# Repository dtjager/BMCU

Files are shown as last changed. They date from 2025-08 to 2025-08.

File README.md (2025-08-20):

My collection of resources for my x1c BMCU build. I noticed everything is not necessarily the easiest to find/sort out, so I put things here as I found them.

[BMCU Wiki](https://wiki.yuekai.fr/)

[Subreddit](https://www.reddit.com/r/BMCU/)

[OpenBambu Subreddit](https://www.reddit.com/r/openbambu/)

[Parts kit I ordered](https://www.aliexpress.us/item/3256809034433237.html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) - 370C A Kit, needed to order PCB's anyway so I figured this was probably the easiest route.

[Filamentalist](https://makerworld.com/en/models/1415066-filamentalist-fv3-rewinder-pc4-m6-mod#profileId-1469469) - for filament rewinding no the X1/P1 printer.

Notes:

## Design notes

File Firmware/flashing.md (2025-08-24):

If you did **not** solder the motherboard yourself, flashing is usually **not required**. Unless you want to upgrade the firmware.

[¶](#️-warning) ⚠️ **WARNING**
------------------------------

🔥 **Before flashing, ensure there are no soldering issues!!!! Check for power short circuits!!!!** 🔥  
🔥 **Before flashing, ensure there are no soldering issues!!!! Check for power short circuits!!!!** 🔥  
🔥 **Before flashing, ensure there are no soldering issues!!!! Check for power short circuits!!!!** 🔥  

[¶](#required-tools) **Required Tools**
---------------------------------------

1.  **Multiple Dupont Wires** (To connect the flasher and the BMCU mainboard).
2.  **USB to Serial Adapter**
3.  **Computer** runs windows. -> If you're using a Mac/Linux, flashing is possible, but I don't have any tutorials or resources for mac.
4.  **Software: WCHISPTool**  
    The classic version used in this tutoriel : [wchisptool-v3.3.7z](/assets/files/wchisptool-v3.3.7z)  
    A newer version : [download at WCH website](https://www.wch-ic.com/downloads/WCHISPTool_Setup_exe.html)

[¶](#flashing-with-uart-ttl-using-ch340) Flashing with UART (TTL) using CH340
=============================================================================

### [¶](#h-1-connect-the-bmcu-mainboard-and-usb-serial-tool) 1. **Connect the BMCU Mainboard and USB Serial Tool**

⚠️ **DO NOT connect the BMCU to the printer during the entire process!**

*   Open the software  
    
    
*   Connect wires according to the wiring instructions.
    
    BMCU
    
    USB Serial Tool
    
    R
    
    TXD
    
    T
    
    RXD
    
    ➕
    
    3V3
    
    ➖
    
    GND

> You may receive a yellow jumper cap, if it is similar to the converter on the right, no need to use it.  
> Connect 3.3V as VCC to the '+' pin on the BMCU mainboard.

  


> If you don't see a serial device here, please install the CH340 chip driver  
> [https://www.arduined.eu/ch340-windows-10-driver-download/#google\_vignette](https://www.arduined.eu/ch340-windows-10-driver-download/#google_vignette)

### [¶](#h-2-connect-the-usb-serial-tool-to-your-pc) 2. **Connect the USB Serial Tool to Your PC**

*   Your computer should recognize the serial port automatically.
*   The COM port number might differ from the example in the image.



* * *

### [¶](#h-3-configure-wchisptool-settings) 3. **Configure WCHISPTool Settings**

Open the `WCHISPTool` software and set the following options:

*   **Chip Model:** `CH32V203`
*   **Download Type:** `SerialPort`
*   **DI – Baud Rate:** `1M`
*   **SerialPort:** Auto-detected (your COM port)
*   **User File:** Choose the firmware `.bin` file (available from our wiki)



* * *

### [¶](#h-4-unlock-the-chip-protection) 4. **Unlock the Chip Protection**

This is a **critical step** before flashing the firmware.

#### [¶](#recommended-method) ✅ Recommended Method:

1.  **Hold down the B button** (do **not** release it throughout).
2.  While holding B, **briefly press the R button** once.
3.  While **still holding B**, click the **"Remove Protect"** button in the WCHISPTool software.  
    

If successful, you’ll see a red **“Unlocked”** message in the tool.  
remove protect successful.png

> ⚠️ If it keeps failing:  
> If you build your own PCB, please always check first for any soldering issues, such as solder bridges on resistor arrays, solder bridges on the CH32V chip, or short circuits in the circuit.
> 
> *   First, try again using the same button sequence carefully, hold always the B button.
> *   Second, **double-click the “Download” button** to force the chip into response mode, then try "Remove Protect" again.
> *   （Rare but indeed some chips will perform like this) try **swapping the TX and RX wires** (i.e., TX-to-TX and RX-to-RX instead of cross).

* * *

### [¶](#h-5-flash-the-firmware) 5. **Flash the Firmware**

Click the **Download** button.

*   Be patient during the process.
*   If flashing is successful, it should look like this:  
    

#### [¶](#️-if-flashing-fails) ⚠️ If Flashing Fails:

*   Try **pressing and holding the B button** while clicking “Download”.
*   Alternatively, try changing the **baud rate to 115200**.
*   In rare cases, try **reversing TX and RX** (TX-to-TX, RX-to-RX) if not already done.

* * *

### [¶](#h-6-reboot-the-board) 6. **Reboot the Board**

*   Press the **R button** once.
*   The **red LED on the mainboard** should now light up.
*   🎉 **Congratulations! Firmware flashing is complete!** 🎉

[¶](#with-type-c-interface) With Type-C interface
=================================================

### [¶](#open-the-software) Open the software



### [¶](#configure-wchisptool-settings) Configure WCHISPTool Settings

Open the `WCHISPTool` software and set the following options:

*   **Chip Model:** `CH32V203`
*   **Download Type:** Still `Serial Port`
*   **DI – Baud Rate:** `1M`
*   **User File:** Choose the firmware `.bin` file (available from our wiki)
*   Tick the "Serial Auto DI" option.



### [¶](#action-sequence) Action sequence

Click : `Remove Protect` -> `Download` -> `Remove Protect` Again -> `Download` Again -> Repeat this loop until done(normolly the second download will be successful, if not check if you done something wrong)  
You might see some error messages during the first loop.

[¶](#using-mac-linux) Using Mac / Linux
=======================================

todo

[¶](#testing) Testing
=====================

**⚠️⚠️⚠️Avoid hot plugging and unplugging the motherboard and printer cables.⚠️⚠️⚠️**  
The right approach（just in case you are not sure what to do):

1.  Power off the printer
2.  Connect the BMCU to the printer
3.  Switch on the printer power
4.  You should see AMS appear in the consumables option, even if you have not inserted consumables, it may show that consumables are present in some channels (known bug)
5.  Power off the printer
6.  Disconnect the BMCU cable

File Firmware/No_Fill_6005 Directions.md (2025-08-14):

Thinking about getting a BMCU? What I've learned!

**Disclaimer:** I'm extremely new to the BMCU system and just finished putting mine together today, so take everything that I say with a grain of salt and proceed at your own risk. With this being said, there were a couple of times throughout the process where I was stumped, so I'd like to share what I've learned and I'll update this post if I ever have to troubleshoot in the future. Just for reference, I have an A1. Also, most of what I write below will be in reference to the version that I have from the specific seller that I bought it from, as well as mostly for the A1. Please let me know if I am wrong about anything that I wrote below, as I just want to make sure that people have an easy introduction into the BMCU.

**Please read my points number 28 and 39 before you even attempt to assemble the BMCU!**

**1\. What is the difference between the BMCU and AMS?** The BMCU and AMS will give you the same results: multi-color printing. However, with this being said, the BMCU is an open-source, non-official Bambulab product. So, technically, Bambu can theoretically release updates that prevent the system from working. But fortunately, as of now, you can always revert back to previous updates on Bambu.  

**2\. What versions does the BMCU work on?** According to the seller that I bought it from, it works with the A1 and A1 mini. It also experimentally works with the P1S P1P, which you can find posts about in the reddit groups that I have listed below. Additionally, it could possibly work with the X1 series but it is unproven.  

**3\. If it's open source, can I just order all the parts separately myself?** Yes, people have done so in the groups that I have listed below, but I personally have not. The good thing about this is that if you order a kit and accidentally break a piece, you can order a specific replacement part (usually for pretty cheap). And just so you know, people also upload replacement pieces on MakerWorld.  

**4\. What's the difference between a BMCUx and BMCUc?** The BMCUc supports bi-directional buffering, making the system softer on your printer.  

**5\. What are some of the other BMCU options?** Some BMCUs use a 130 motor while others use a 370 motor. Additionally, some use glass bearings and some use steel bearings. I'm not really sure what the difference is, but the one I ordered has a 370 motor and glass bearings.  

**6\. Where did you buy yours from?** I bought Set A from this link: [**https://www.aliexpress.us/item/3256809034433237.html?spm=a2g0o.order\_list.order\_list\_main.5.49ea1802L3PVEx&gatewayAdapt=glo2usa#nav-specification**](https://www.aliexpress.us/item/3256809034433237.html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)  

**7\. What is the difference between Set A vs Set C?** Set A is for those that want to print in up to 4 colors. Set C is typically bought by those that have print farms and only want the option of having two spools in case one runs out as a backup, because to them, time is money, rather than having the option of printing 4 colors.  

**8\. How hard is it to assemble?** Not hard at all, _but you'll need a soldering iron and solder (aka wire meant for soldering)._ If it's your first time soldering, don't worry. It was my first time ever dealing with electronics or soldering. I'll post some reference videos below. Also, here are some tools that I would recommend printing to help you with soldering. Links: [https://www.printables.com/model/843353-solder-scroll-ergonomic-adjustable-solder-tool](https://www.printables.com/model/843353-solder-scroll-ergonomic-adjustable-solder-tool) and [https://makerworld.com/en/models/487984-soldering-tool-holder-flexible-arms-helping-hands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](https://makerworld.com/en/models/487984-soldering-tool-holder-flexible-arms-helping-hands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)  

**9\. Why does the seller that you bought it from have another kit with the same title and description, but sometimes different prices?** To be honest, no idea. But, if someone knows why, post it in the comments of this post so that others can learn from it.  

**10\. Where can I find the instructions for the kit that you purchased?** This drive contains the instructions, firmware, and STLs from the seller. Also, people recommend to print the pieces in PETG. Link: [https://drive.google.com/drive/folders/1XAFt80xYqbaAVDwtqItvBLUezMbsYlGM](https://drive.google.com/drive/folders/1XAFt80xYqbaAVDwtqItvBLUezMbsYlGM)

**11\. I'm limited on space. Is there a print that will allow me to mount both the spools and the BMCU on my A1?** Yup, there sure is! Go to the link I will paste, print it out of PETG, and select the print profile by me, TheHerd, on MakerWorld, if you have an A1 and are confused about which pieces are compatible with it and don't feel like arranging the pieces to fit on your A1 build plate. Don't worry, the original creator still gets the points. And, instead of screwing it, I used mounting tape from the Gorilla brand because I didn't want to risk my model not being compatible with where they wanted me to screw it in. And, just and fyi, it is fine to print out the PTFE supports with PLA instead of PETG. You can find that stl in the Google drive folder that I posted the link to in my 10th bullet point. Link: [https://makerworld.com/en/models/1429013-bmcu-stand-for-a1-a1-mini-ams-lite-vertical-mount#profileId-1485599](https://makerworld.com/en/models/1429013-bmcu-stand-for-a1-a1-mini-ams-lite-vertical-mount#profileId-1485599)  

**12\. Won't adding all that weight be rough on my printer?** Probably, so you may want to print out these Z-axis supports in PETG from the link I will paste if you have an A1. Print the print profile that is titled "A1 mini Big feet" instead of the one from the creator, as you only need the bottom part. Don't worry about the title saying it's for the mini. Link: [https://makerworld.com/en/models/92486-ams-lite-top-mount-for-a1#profileId-100105](https://makerworld.com/en/models/92486-ams-lite-top-mount-for-a1#profileId-100105)

**13\. Where are some good resources if I want to ask questions about the BMCU?** [https://www.reddit.com/r/OpenBambu/](https://www.reddit.com/r/OpenBambu/) and [https://www.reddit.com/r/BMCU/](https://www.reddit.com/r/BMCU/)  

**14.** **One of the bushings that BLV mentioned in Step 4 of the assembly guide isn't fitting. What do I do?** Yup, and it won't ever fit perfectly in there for some reason, no matter how many times you reprint the STL. Not saying that you should superglue it, but that's what I did. Try and find glue that is heat and vibration resistant.  

**15.** **I'm on Step 5 of the assembly guide and don't know how to solder. Help!** First of all, I'd recommend using the part of the tool that I have the arrow point to to strip the wire. Place the wire where the arrow is pointing, then pull it. Second of all, personally, before I add solder to the wire, I twist the "hairs" so they aren't "frazzled". Make sure to strip and add solder to both ends of the wire. It's a surprise tool that will help us later. Here's the link that I used to learn how to solder for the motor: [https://youtu.be/XkpGsMpGGqQ?si=qGBOIP5blRSgvldF](https://youtu.be/XkpGsMpGGqQ?si=qGBOIP5blRSgvldF) . While the video says to place the black wire on the red dot, and it technically doesn't matter if you solder it to the negative on the daughter board. However, I'd highly recommend just keeping it aligned with the instructions and SOLDERING RED TO RED.

r/OpenBambu - Thinking about getting a BMCU? What I've learned! (https://preview.redd.it/thinking-about-getting-a-bmcu-what-ive-learned-v0-tdrll9tojlff1.png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 "Image from r/OpenBambu - Thinking about getting a BMCU? What I've learned!")

**16\. I'm on Step 8 of the assembly guide. What does BLV mean when they say "with the pointed end facing up"?** They just mean to place the hex nut in vertically rather than horizontally.  

**17\. I'm on Step 9 and the slider isn't moving easily.** **What do I do?** You likely just need to shave the sides of the slider. I used a wood carving tool, personally, but you can probably just file it down or use sand paper.  

**18\. What in the world is BLV talking about in Step 10?** In the bag, there are two pieces that look very similar and seem to have the same diameter. For this step, the assembly guide is wanting you to take out the one with the black screw on the side. You'll have to take out the screw before you can insert the shaft then screw it back once you've already inserted it.  

**19\. In Step 12, does the filament seem to face a little resistance even though I can still push it through?** Yup, you didn't do anything wrong. There are little teeth inside of the metal outlet that causes this.  

**20\. I'm on Step 20 of the assembly guide. How do I do this now?** Watch this video. It is okay if you get some metal on the black part, but make sure not to let the metal from the positive end and negative end touch one another. [**https://youtu.be/y0xDR3St5Gg?si=RhCsTe45R3gjiS3f**](https://youtu.be/y0xDR3St5Gg?si=RhCsTe45R3gjiS3f)  

**21\. I accidentally got grease on the end of the solder wire. What do I do?** Use some rubbing alcohol to wipe, get a clean napkin and wipe off the alcohol, then wait for the rest to evaporate. The alcohol will evaporate quickly.  

**22\. In step 22, it says that I should feel a bend. What bend?** You'll just feel a slight resistance, but not anything that screams "bend".  

**23\. Did you have leftover parts when you finished?** Yup!  

**24\. When you plug in the BMCU, which port on the back of the A1 do you use?** Doesn't matter, they're the exact same!

**25\. Why is the AMS screen on my printer appearing but not giving me any options to load, unload, or edit?** You have to push the filament all the way through the BMCU first, but don't go all the way to the actual print head. Once you pass it through the BMCU, you'll have the options to load, which is when you need to push it all the way to the print head.

**26\. Huh, what do they mean in step 27 when they say to push on the slider vs when they say to pull on the slider?** So, what the assembly manual really means, is that you need to push down on the trigger thingy until the printer says that it has finished loading. If you release the trigger before it has completed loading, it will pull the filament back towards the spool rather than towards the print head. With this being said, before you actually load the filament (refer to my 25th point), you need to press the trigger just to load the filament all the way through the BMCU. After doing so, you can release the trigger. Then, on the printer, click load. One the screen says to push in the filament, you MUST press the trigger the entire time while you are pushing it through the print head. Keep holding it until it moves on to the purge step. After it reaches the purge step, you can release the trigger.  

**27\. In step 30 of the assembly guide, when it says to not cut the PTFE tubes too short, what exactly does that mean?** So, quick tip, I went to "controls" on the printer and moved the hot end all the way to the left because the furthest slot was towards the right. That gave me the maximum length that I needed for the PTFE tube, roughly. Make sure to account for the fact that a small portion of the tube will be hidden in the BMCU and print head. For the mount that I pasted a link to, I put the mount roughly in the middle (I tried to center it but it was a little to the left), and the longest strand I need was 33 inches.

**28\. How do I remove the cord from the back?** _BEFORE YOU EVEN PLUG IN THE BMCU, PRINT THIS TOOL TO REMOVE THE WIRE!!!!_ Even with this tool, I had to use quite a bit of force, and I tend to be rough on things. I printed the tool out of PETG and used 100%% infill. Link: [https://www.printables.com/model/382058-bambu-ams-disconnect-tool](https://www.printables.com/model/382058-bambu-ams-disconnect-tool)

**29\. When I try to unload filament, it just pushes more filament further**. **What do I do?** When you unload the filament, when it says to "pull back current filament" on the printer screen, you have to press the trigger.

**30\. I'm trying to unload the filament and I am pressing the trigger, but it still won't let me unload it. What do I do?** Turn off your printer then unplug the cord from the back (reference my 31st bullet). After doing so, turn your printer back on. Then, even though the AMS option won't show up, this is what we want. Click unload filament from a single roll like you had done before the BMCU. This will allow you to remove all the filaments. When finished removing the filament, turn your printer off again, then plug the BMCU back in, turn the printer on and proceed normally.

**31\. The printer keeps clogging. Help!** It is probably because even regular AMS systems are known for clogging what is apparently called "the filament hub". I didn't think that mine was clogged, and nothing seemed to have come out, but it apparently worked. Watch this video to see how to unclog it. The video also features unclogging the hot end. If it is your first time removing the filament hub, you're probably going to have to use a little more force than what's shown in the video. Link: [https://www.youtube.com/watch?v=cNBu2mcOH8E](https://www.youtube.com/watch?v=cNBu2mcOH8E) . Also, if you notice that the filament seems brittle, dry it. I noticed that PLA I had never had problems with in the past kept breaking. If you need a dryer, I would recommend buying one from Creality. While I have heard not to buy printers from them, their dryers work fine. Sometimes, people sell them for really cheap on Facebook Marketplace (saw one for $25).

**32\. How do I actually load all 4 spools?** Someone had to help me with this, and I still probably added too many extra steps for myself, but here is what I did, and it at least worked. LOL

*   Press down on the trigger and push the filament into the bottom of the module you’re trying to load. Keep going until the filament light turns on. (Earlier, I mentioned pushing it until you can see it come out the other side—sometimes the filament can get stuck in the buffer section with the spring, so just make sure it’s made it through.)
    
*   If you just want to check that the module works, you can load the filament straight into the extruder using the printer’s touchscreen—no need to mess with the slicer yet.
    
*   Once you’ve tested that loading and unloading works for all the modules, go ahead and unload the last filament you tested. If I remember right, it won’t fully eject—and that’s okay. Just leave it as is.
    
*   Turn off the printer, then push filament through the BMCU for all modules, but not all the way to the print head. Then, turn the printer back on.
    
*   Now you can go into Bambu Studio, pick the filament or filaments you want to use, and start your print. The printer will take care of all the loading and unloading automatically based on what you picked.
    
*   Make sure that the filament type that you enter into the slicer is the same as the filament AMS screen on your printer (even though you should NOT click "load"). Just click "edit"

**33\. Why in the world will the PTFE tubes not stay connected to the filament hub?!** This is apparently another common problem even with the official AMS. It will seem unreasonably difficult to pull apart if it is your first time removing it. Watch this video: [https://www.youtube.com/watch?v=hmByMHddxLE](https://www.youtube.com/watch?v=hmByMHddxLE)

**34\. I took out the hot end and now I can't get the latch back on, what do I do?** I don't know why this works, but it does. On your printer, go to "Control", click "Nozzle", then enter 200. Once you see that the nozzle has heated up to 200 degrees, use pliers to close the latch. BE CAREFUL! IT WILL BE HOT!! Once you've gotten the latch on, change the nozzle temperature to 0 degrees. Don't worry, it won't actually change it to 0 degrees, it will just stop applying heat so that the hot end will reach room temperature. I'd also recommend printing a fan cover for the side of the A1 print head, as I always tend to try to grip there. It shouldn't be hot, but I don't want to wear out the motor by accidentally stopping the fan with my hands.

**35\. Why did the motor of one of the modules stop running when trying to feed filament?** Turn off the printer and remove the PTFE tube from the print head. Hold the trigger of the module and try manually feeding it through the tube. If it is hard to do, you have a bend in your PTFE tube. Try to unbend it, then if you can't, cut it.

**36 I'm trying to print a multicolor model. Why do the colors look fine in the "Prepare" tab but change when I go to the "Preview" tab?** The "Preview" tab colors aren't the actual colors that the model will be printed in. The colors just represent different parts of the print, such as thin walls, overhang, etc.

**37\. How do I "color" my models for the BMCU?** This video helped me: [https://youtu.be/5aJZyhfY74s?si=KYn5aTZj5bulu6uI](https://youtu.be/5aJZyhfY74s?si=KYn5aTZj5bulu6uI)

**38\. How do I "color" prints that are flush, like logos?** Here's a detailed, yet short video: [https://www.youtube.com/watch?v=em\_t5sK13CM](https://www.youtube.com/watch?v=em_t5sK13CM)

**39.** **Are there replacement pieces that I should print just in case?** Yes, there absolutely are! I'd recommend printing a spare of each of these before even attempting to connect the BMCU to your printer.

*   Filament hub cap: [https://makerworld.com/en/models/745171-ams-lite-hub-cap-4-way-replacement-a1#profileId-1072550](https://makerworld.com/en/models/745171-ams-lite-hub-cap-4-way-replacement-a1#profileId-1072550)
    
*   Filament hub connector: [https://makerworld.com/en/models/1105767-bambu-ams-lite-filament-hub-connector#profileId-1173093](https://makerworld.com/en/models/1105767-bambu-ams-lite-filament-hub-connector#profileId-1173093)

Please make sure to print the spare filament hub cap and filament hub connector. The below aren't necessary, but are definitely recommended to help prevent you from needing a spare in the first place.

*   Filament hub connector and PTFE tube removal tool: [https://makerworld.com/en/models/1267494-amazing-a1-and-a1-mini-ams-hub-tool#profileId-1293506](https://makerworld.com/en/models/1267494-amazing-a1-and-a1-mini-ams-hub-tool#profileId-1293506)
    
*   Cable Clips: [https://makerworld.com/en/models/1277493-a1-cable-clip-1-1-replacement?from=search#profileId-1305146](https://makerworld.com/en/models/1277493-a1-cable-clip-1-1-replacement?from=search#profileId-1305146)

Hopefully this helps someone :)

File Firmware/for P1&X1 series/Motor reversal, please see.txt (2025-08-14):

If your motor always rotates in the opposite direction under the current firmware, even if there is nothing wrong with your wiring, please solder the motor wires in reverse before using it, unless this problem is fixed in future firmware (the function of automatically determining the forward and reverse direction is removed).

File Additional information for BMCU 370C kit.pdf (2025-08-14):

## ·Additional information for BMCU 370C TL kit

1. The kit you purchased is BMCU370C derived from the open

source BMCU project. Although the 130motor version release

first, but the official no longer provides follow-up development.

Future versions will mainly be based on the 370motor version.

The BMCU project address is here: https://bmcu.wanzii.cn

2. This kit (BMCU370C-TL) adds a rod guide to the original to

smooth the action and extend life, all other parts are the same as

the original version, if you want to assemble it strictly according to

the parts of the original version.

3. This is not an officially certified project by Bambu-Lab, so it may

become unusable at any time due to the printer's firmware

upgrade. We do not make any form of guarantee for this.

4. Due to regulations regarding mailing packages, some kits may

not contain grease. You will need to find a bit of grease that is

suitable for plastic gears. We already put some grease on the

gears, so it doesn't matter if you can't find the grease.

5. The control boards have been flashed with firmware before

shipping. And they have been fully tested.

6. Warning: Always turn off the power before plugging or

unplugging the AMS cable, otherwise it may cause permanent

damage to the printer or BMCU.

7. Warning: Before you turn off the printer, make sure that no

filament is loaded into the tool head. Otherwise, when you load

or unload the filament again when you turn on the printer next

time, the error warning "Falled to check the filament location" will

appear.

8. The kit file download link:

https://drive.google.com/drive/folders/1XAFt80xYqbaAVDwtqItvBLUezMbsYlGM

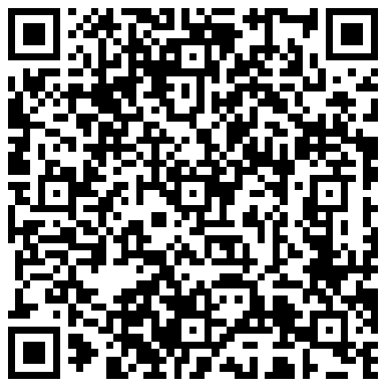
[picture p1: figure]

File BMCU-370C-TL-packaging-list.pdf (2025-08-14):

| Component | Qty.
Electronics | RF370 DC motor 24V 6000RPM | 4
| Mother board (type-C) | 1
| Daughter board (BMCU370C) | 4
| 10P Rainbow cable | 4
| AMS Connecting cables 80cm | 1
| Motor wires | 0.5M
Filament drive gear | Filament drive gear (bmg sytle) | 8
| Needle Roller Bearings | 8
| 682A Worm gear | 6
| 182A Gear | 12
| 62B Bushing | 40
| Shaft D5L22mm | 4
| Shaft D3L20mm | 4
| Shaft D2L20mm | 16
| Shaft D2L40mm | 4
| Bearings MR85ZZ | 8
Fastener | M3*5 Flat head screw | 4
| M3*14 Countersunk screws black | 5
| M3 hex nut black | 5
| M2*8 Countersunk self-tapping screws | 60
| M3*14 Countersunk self-tapping screws | 8
Misc | Spring 0.8D12L25 | 8
| Spring 0.6D4L15 | 4
| Spring 0.3D4L5 | 4
| Transparent filament 50CM | 1
| PC4-M6 Pneumatic Connector | 8
| D6H2.5 Radial Magnetic Field Magnet | 4
| D3H10 Magnet | 8
| D5 Glass ball | 6
| PTFE TUBE 4*2.5MM | 5M
version 19-6-2025

## BMCU 370C TL 4-Channel MMU for A1&P1 Series printer-Packaging-List

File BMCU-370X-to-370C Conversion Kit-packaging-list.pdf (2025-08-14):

Component | Qty.
Daughter board (BMCU370C) | 4
10P Rainbow cable | 1
62B Bushing | 10
Shaft D2L40mm | 4
M2*8 Countersunk self-tapping screws | 4
Spring 0.8D12L25 | 8
Spring 0.3D4L5 | 4
Transparent filament 50CM | 1
D3H10 Magnet | 8

## BMCU-370X-to-370C Conversion Kitpackaging-list

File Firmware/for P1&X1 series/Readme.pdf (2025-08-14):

This version of the firmware of BMCU370C is divided into

two 4-in-1 series, internal and external. If you want to install

the 4-in-1 adapter near the print head, similar to the style

of A1(Figure 1), so that you can change the filament as

quickly as possible, then you have to flash the internal

version of the firmware. If you install the 4-in-1 adapter

outside the chassis, similar to the traditional AMS used by

P1X1, then you have to flash the external firmware (Figure

2).

The same version of the firmware has four suffix ABCD,

which are used to distinguish the identification numbers of

four different BMCUs connected in parallel on the same

printer. In other words, you can install four BMCUs on your

P1X1, flash the four firmwares ABCD respectively, and

simply connect the cables in parallel to achieve the AMS

function of 16 channels. (Figure 3). Please do not try this on

the A1/A1 mini, as it is not possible for the A1 to support

more than 4 channels.

Figure 1:

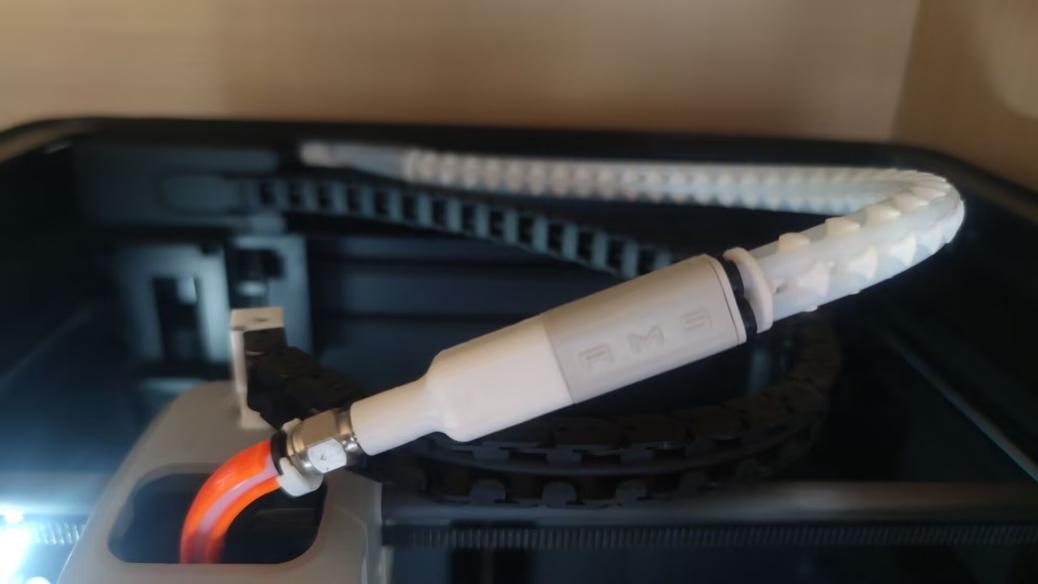
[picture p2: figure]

Figure 2:

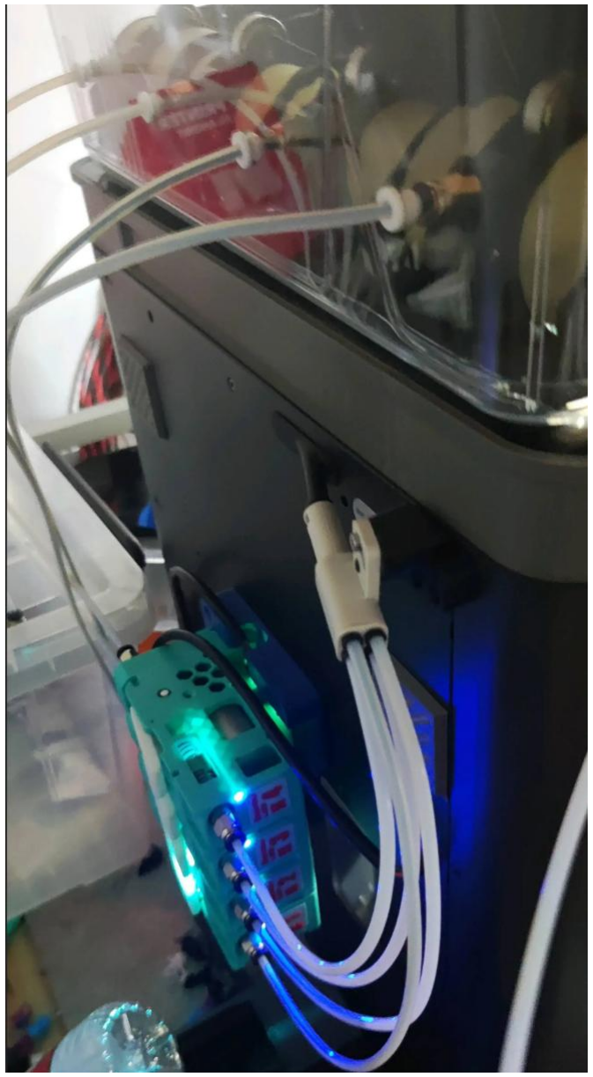
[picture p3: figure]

Figure 3:

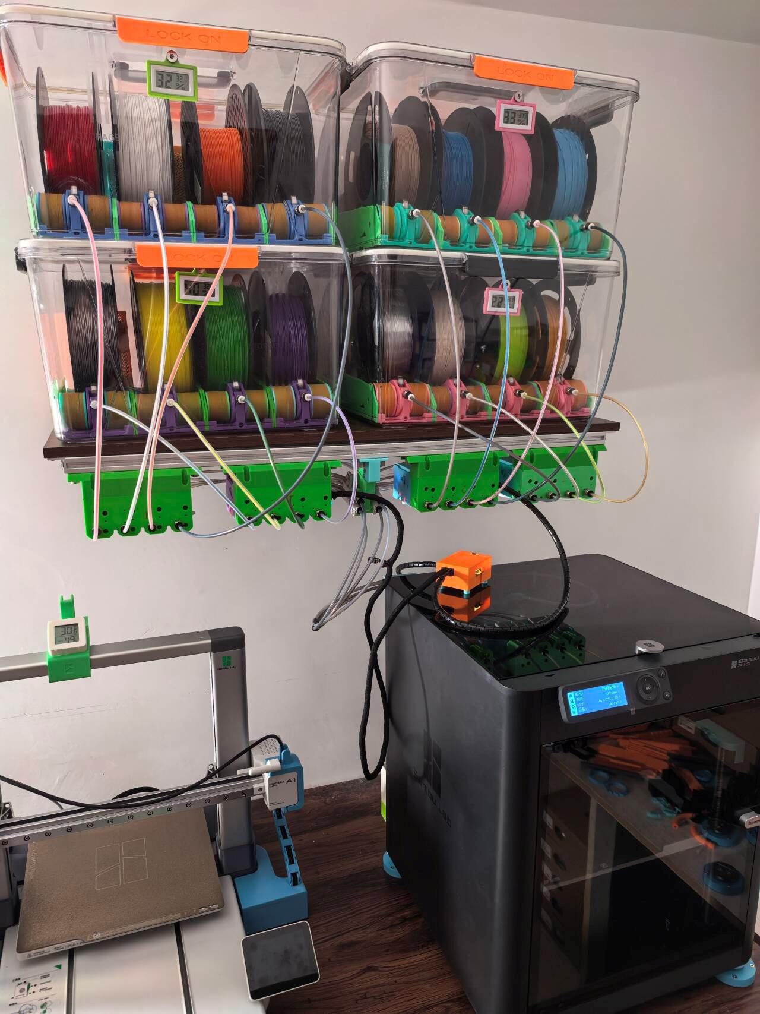
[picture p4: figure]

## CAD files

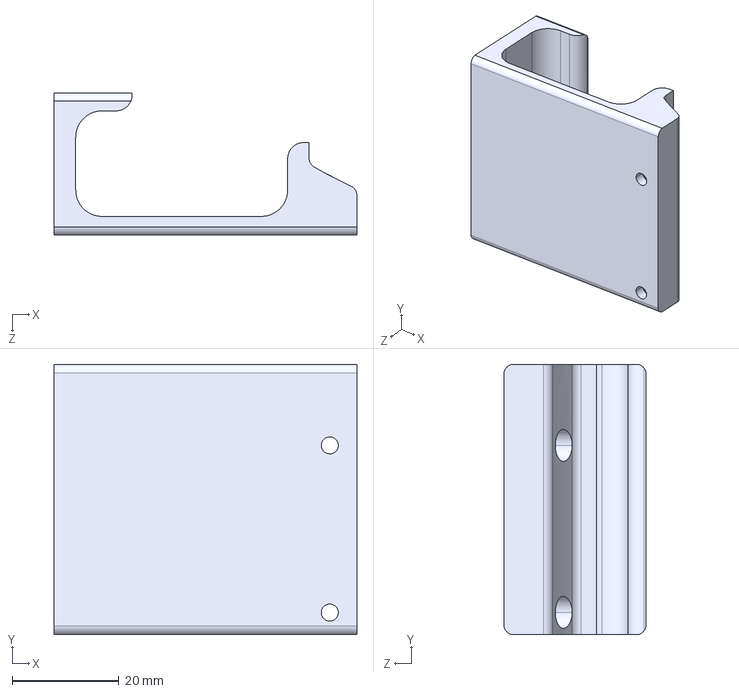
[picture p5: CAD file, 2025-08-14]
STL's/Accessories and Mounting Brackets/Mounting Bracket for A1.STEP
56.9 x 50.7 x 26.7 mm

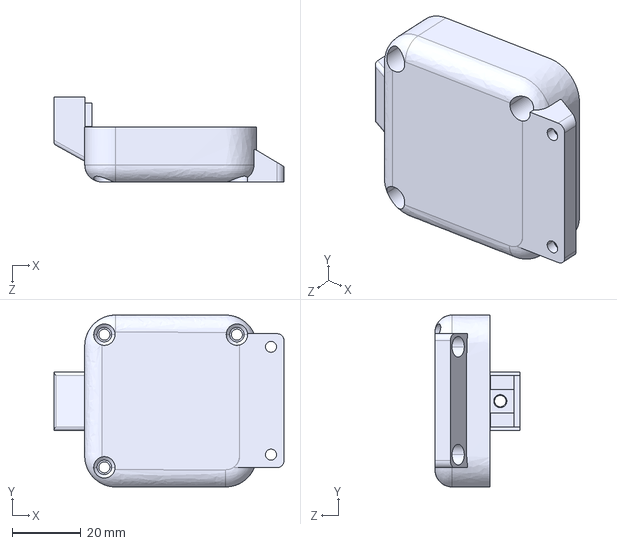
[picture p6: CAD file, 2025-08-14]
STL's/Accessories and Mounting Brackets/Mounting Bracket for A1mini.STEP
66.9 x 50.0 x 24.7 mm

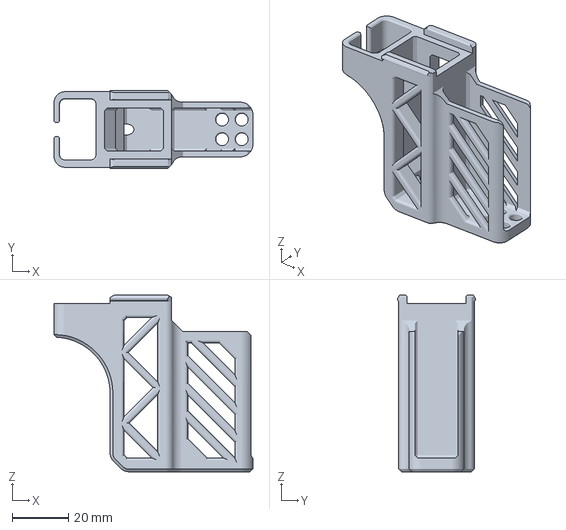
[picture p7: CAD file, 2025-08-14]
STL's/Accessories and Mounting Brackets/AMS lite Filament Hub protector.3mf
71.0 x 28.0 x 63.0 mm

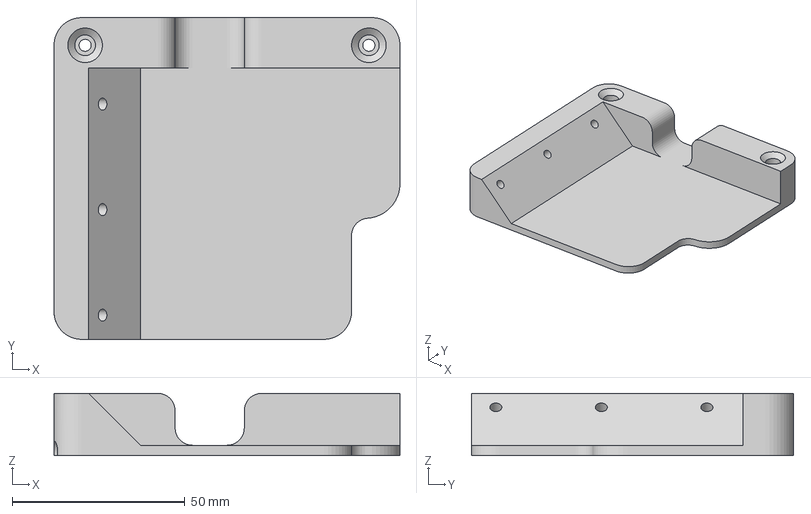
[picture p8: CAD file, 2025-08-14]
STL's/Accessories and Mounting Brackets/Support bracket for P1 series.3mf
100.0 x 93.0 x 18.0 mm

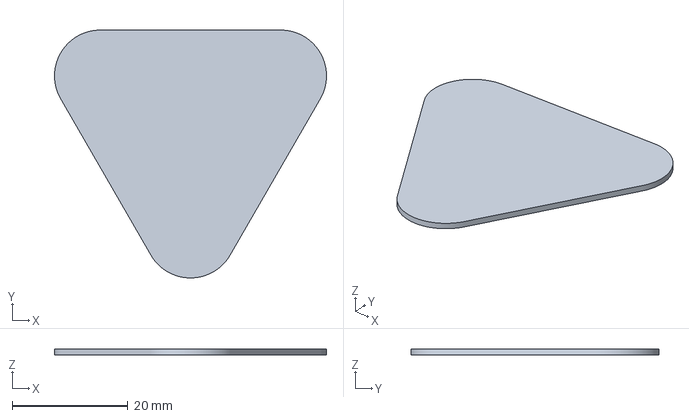
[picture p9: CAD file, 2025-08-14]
STL's/Accessories and Mounting Brackets/AMS-lite A1&A1mini 4 color test.3mf
47.1 x 42.9 x 1.00 mm

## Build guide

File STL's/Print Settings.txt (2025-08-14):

slicer setting
layer height 	0.2mm  		0.16-0.24mm will works too
walls 3
infill density 30%

filament type
PETG is recommended
PLA Works but not recommended
ABS not tested, should work
Please do not use transparent or translucent filament to print it.
"BMCU-370C-TL-Buffer-Slider", this part needs a little support
It is recommended to print a unit first and assemble and test it.

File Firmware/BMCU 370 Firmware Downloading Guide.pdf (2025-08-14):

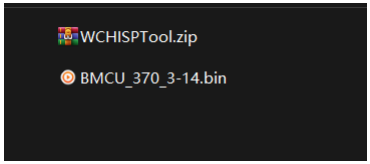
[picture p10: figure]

Official Website: www.trianglelab.net | trianglelab.aliexpress.com

Triangle-lab®

BMCU 370 Firmware Downloading Guide

1. Whether you purchased a kit or a fully assembled BMCU the main

board has been flashed with the latest firmware and has been fully

tested. So you will only need to use this tutorial if you need to flash

a newer firmware or troubleshoot a problem.

2. To flash the firmware to the BMCU main board, you need a Windows

PC, the tool WCHISPTool, and the compiled firmware bin file. Usually

the source code file will be released at the same time. If you don’t

know what the source file is, you can ignore it.

3. Disconnect the AMS cable from the BMCU and connect the BMCU

main board and the PC with a USB-C cable.

4. Open WCHISPTool.exe in the WCHISPTool directory. You will see the

following interface.

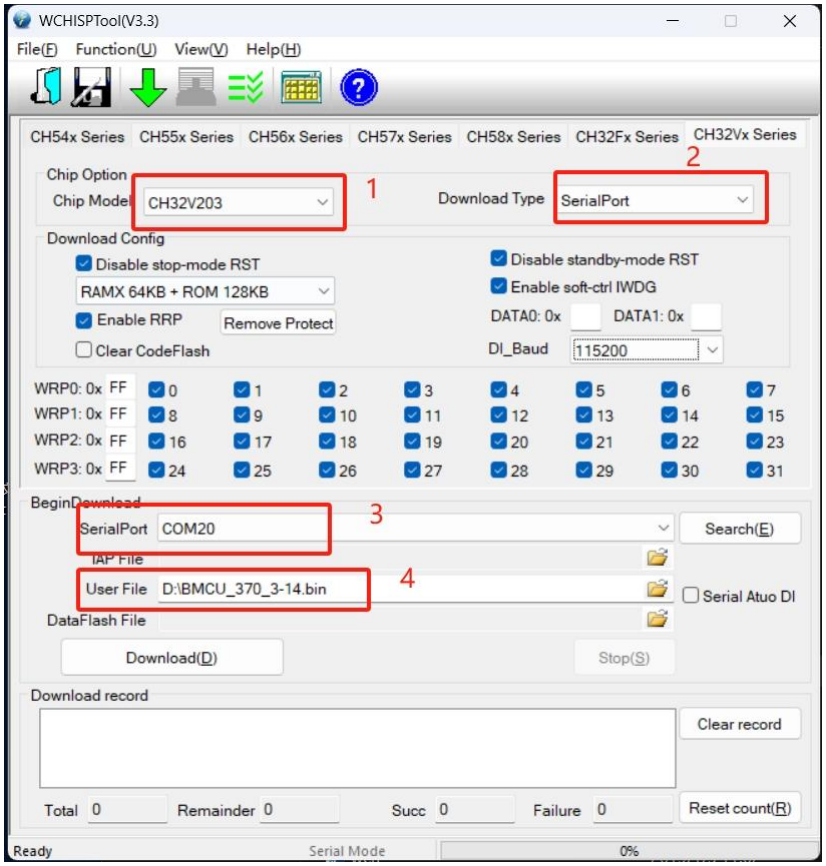
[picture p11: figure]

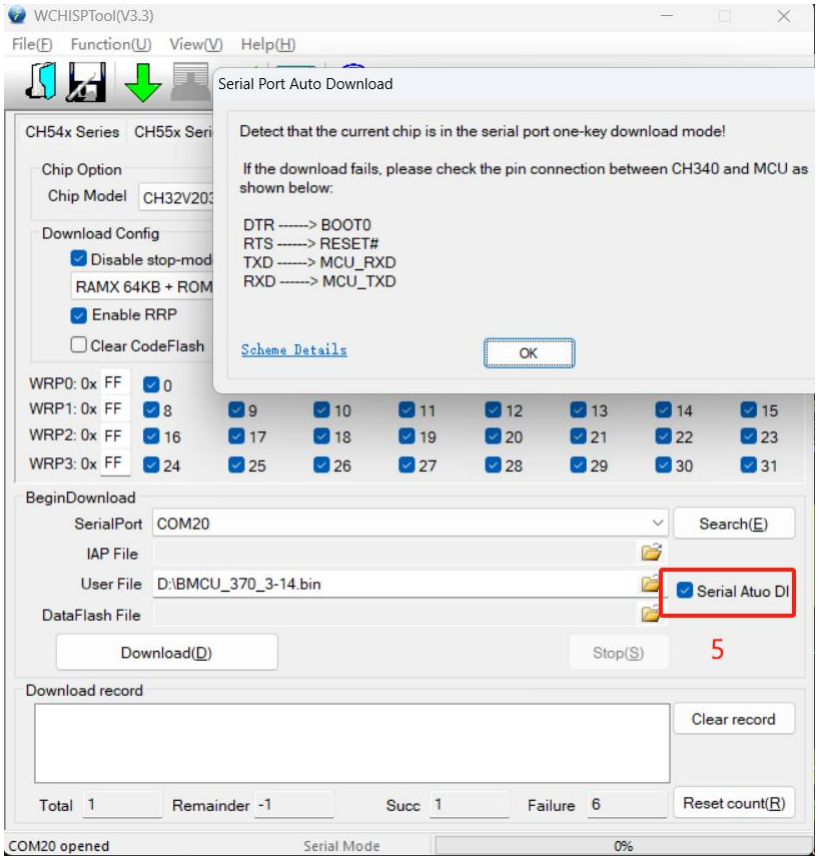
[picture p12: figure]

1- Select CH32V203

2- Select SerialPort

3- Select After plugging in the board, just select the extra COM port

on your PC.

4- Select the firmware file with the suffix BIN that you got.

5- Select Serial auto download and click OK

5. Click Remove Protect

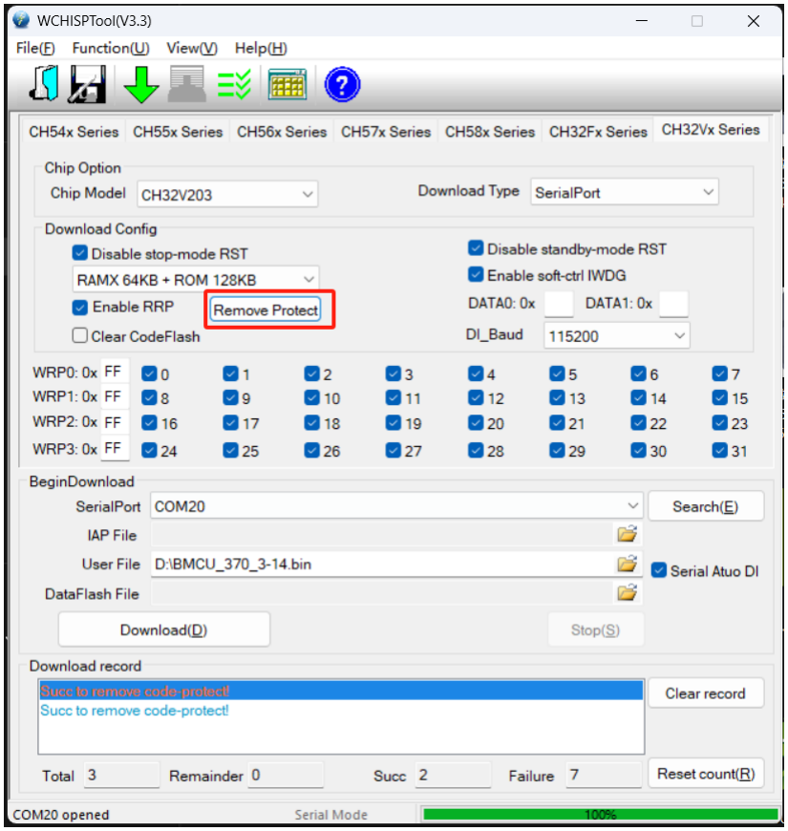
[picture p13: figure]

6. Click Download button. If nothing goes wrong, you can flash the

firmware. Just wait for it to be completed and unplug the Bmcu board.

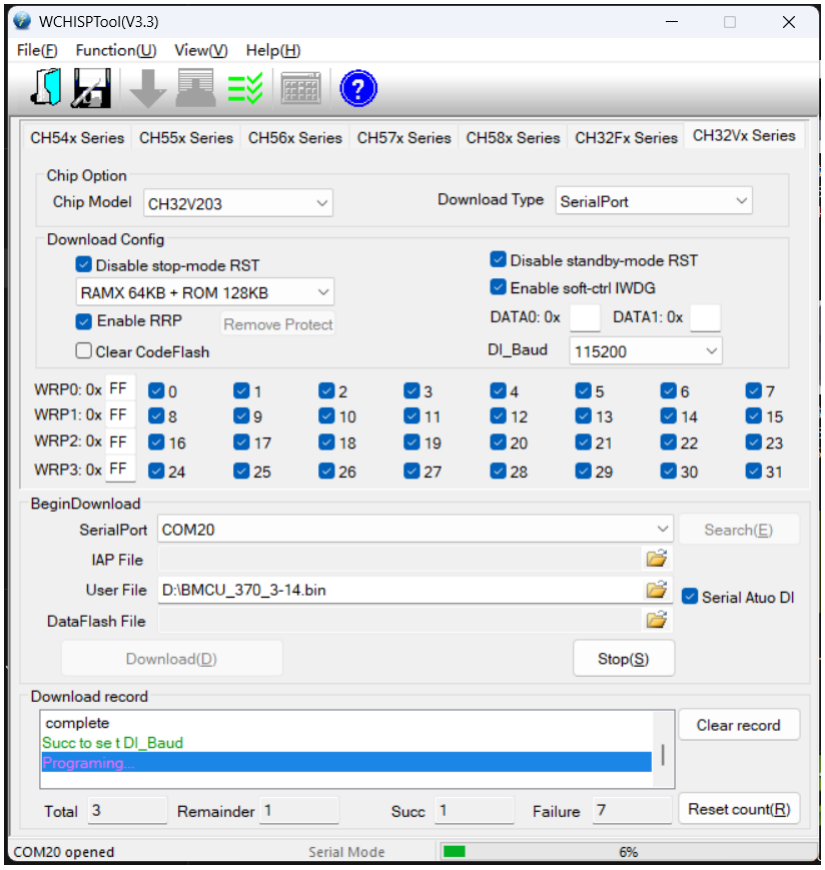
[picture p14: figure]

7. If you cannot find new COM port, you can check and replace the USB

cable and the USB interface on the PC. It is also possible that the older

Windows version does not automatically install the driver for the

CH340 USB to serial port chip.

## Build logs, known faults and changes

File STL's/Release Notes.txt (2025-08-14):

这个模型在官方0.2版本的基础上进行了一些修改和优化

版本R2
-机身上把手弹簧的沉孔变浅了1mm，增加把手弹簧的压力，防止耗材驱动轮打滑，增加耗材驱动力
-缩小了灯丝传感器光电开关的开孔上的倒角，避免之前一定概率出现的误触发
-滑块上的衬套安装位置加深了，避免安装后法兰高出平面

版本R1 
日期20250701
-减小电机蜗杆和齿轮的间距(0.1mm)，延长了齿轮和蜗杆的服役时间
-缩小了电机固定位置，把电机固定得更紧一点
-为缓冲滑块增加了一个D2L40MM的导向轴，让缓冲动作更加顺滑减少打印件之间的磨损
-整体厚度缩短了0.1mm固定在底座上的时候会更容易点
-增大PCB盖板的螺丝沉孔，防止螺丝头凸出来
-调整了一些螺丝的孔位，固定螺丝牢固
-电机出线的孔位加大，更加方便出线和焊接
-电机附近的孔位增大，有利于电机散热
-增加了灯丝传感器光电开关的开孔，防止碎屑堵塞造成误判
-把手转轴的孔壁厚增加

This model has been modified and optimized based on the official version 0.2
Version R2
Date 11-AUG-2025
-The countersink for the handle spring on the body has been shallowed by 1mm to increase the spring pressure, prevent the filament drive wheel from slipping, and increase the filament drive force.
-The chamfer on the opening of the filament sensor photoelectric switch has been reduced to prevent false triggering.
-The mounting position of the bushing on the buffer slider has been deepened to prevent the flange from protruding above the surface after installation.

Version R1

Date 01-JULY-2025
-Reduce the distance between the motor worm and the gear (0.1mm), and extend the service life of the gears and worm
-Reduce the motor fixing position and fix the motor tighter
-Add a D2L40MM guide shaft to the buffer slider to make the buffer action smoother and reduce the wear between the printed parts
-The overall thickness is shortened by 0.2mm, which will be easier to fix on the base
-Enlarge the screw countersunk hole of the PCB cover to prevent the screw head from protruding
-Adjust the hole position of some screws to fix the screws firmly
-The hole of the motor wire is enlarged, which is more convenient for outlet and soldering
-The hole near the motor is enlarged, which is conducive to the heat dissipation of the motor
-Increase the opening of the filament sensor photoelectric switch to prevent debris from clogging and causing misjudgment
-Increase the wall thickness of the handle shaft
